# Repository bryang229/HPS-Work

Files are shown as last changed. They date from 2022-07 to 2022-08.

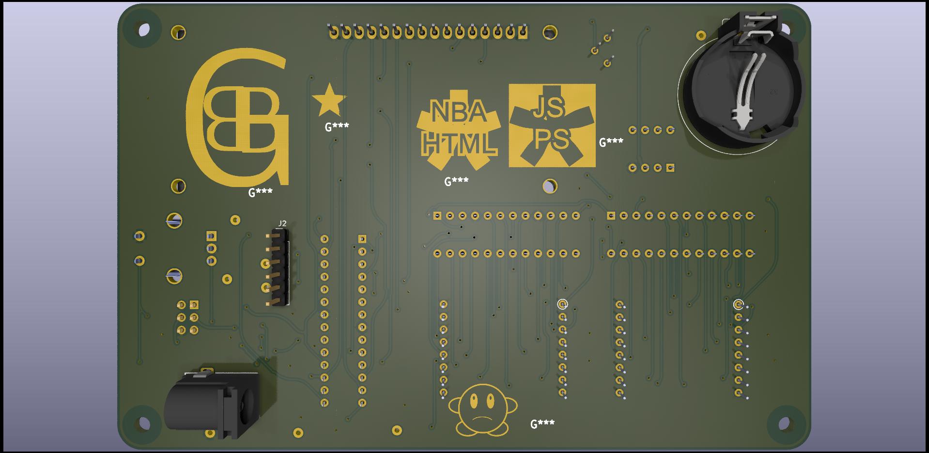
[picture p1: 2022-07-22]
Clock CAD & Code/Clock/Clock backside raytracing.jpg

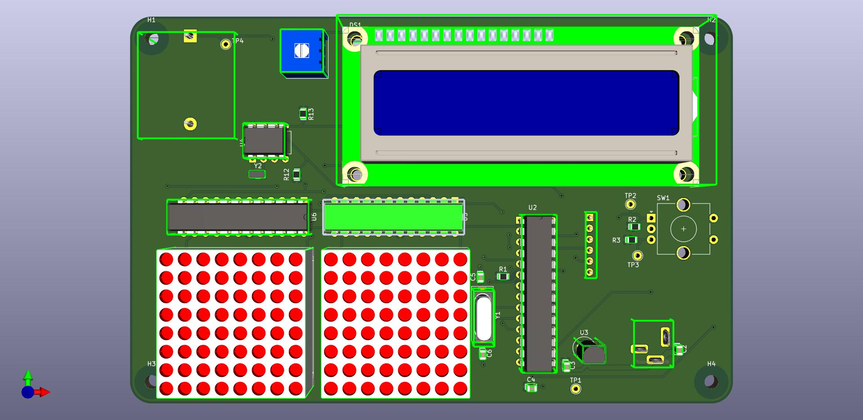
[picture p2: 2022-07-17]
Clock CAD & Code/Clock/Clock.jpg

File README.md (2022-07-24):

# About

This is a Clock PCB designed using KiCAD!

The code working with the clock is also included written in the arduino editor!

All parts in the clock are from [this library](https://github.com/hps-matthew/hps-kicad-library) (very useful !).

This is a project under the Hardware Product Spring program ! (Hence HPS) 

More documentation about the code is to come.

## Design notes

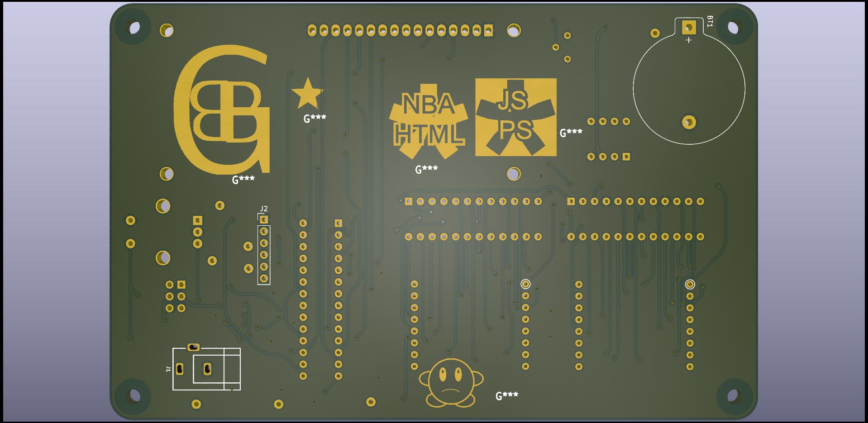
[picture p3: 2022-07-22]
Clock CAD & Code/Clock/Clock Back PCB.jpg

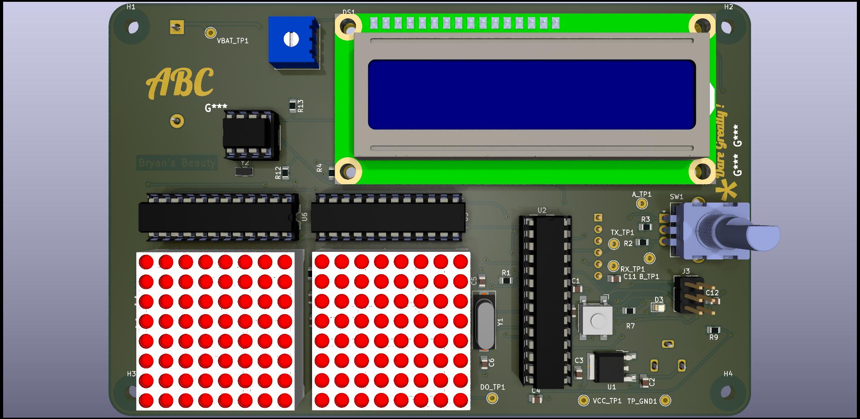
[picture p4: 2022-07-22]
Clock CAD & Code/Clock/Clock raytracing.jpg

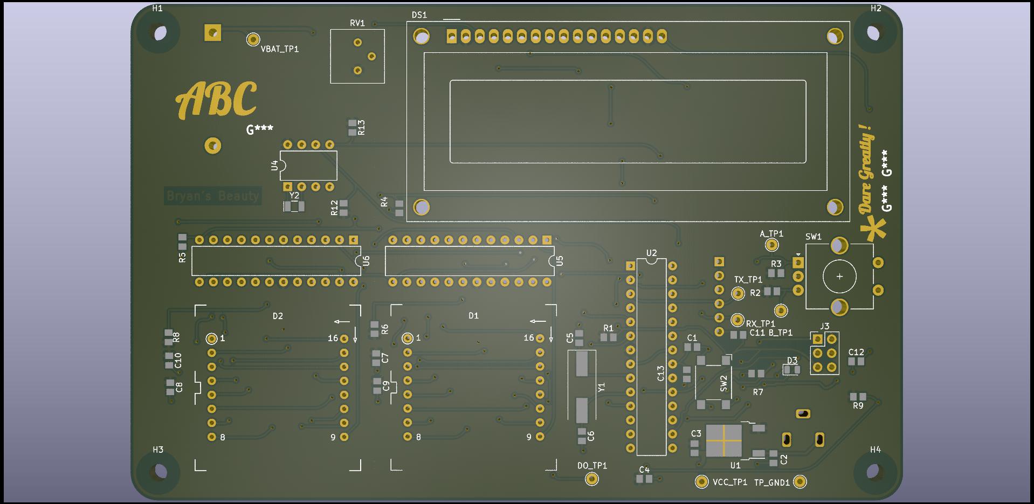
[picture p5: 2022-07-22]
Clock CAD & Code/Clock/Clock Front PCB.jpg

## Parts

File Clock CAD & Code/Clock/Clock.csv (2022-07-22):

Id | Designator | Package | Quantity | Designation | Supplier and ref
1 | C11,C13,C3,C10,C4,C9,C1 | C_0805_2012Metric | 7 | C_0805_0.1uf
2 | Y2 | Crystal_SMD_2Pin_3.2x1.5mm | 1 | Crystal_32768Hz
3 | R1 | R_0805_2012Metric | 1 | 10KΩ
4 | U5,U6 | DIP-24_W7.62mm | 2 | MAX7219
5 | H2,H3,H1,H4 | MountingHole_3.2mm_M3 | 4 | MountingHole
6 | C6,C5 | C_0805_2012Metric | 2 | 22p
7 | SW1 | RotaryEncoder_TT_EN11-Switch_Vertical_H20mm_CircularMountingHoles | 1 | RotaryEncoder_Switch
8 | R7 | R_0805_2012Metric | 1 | R_0805_2.2K
9 | R6,R8 | R_0805_2012Metric | 2 | R_0805_22K
10 | A_TP1,DO_TP1,TX_TP1,VCC_TP1,RX_TP1,B_TP1,VBAT_TP1,TP_GND1 | TestPoint_THTPad_D2.0mm_Drill1.0mm | 8 | TestPoint
11 | U1 | TO-252-2 | 1 | L7805
12 | R2,R4,R9,R5,R3 | R_0805_2012Metric | 5 | R_0805_10K
13 | Y1 | Crystal_SMD_HC49-SD | 1 | Crystal 16MHZ
14 | D3 | LED_0805_2012Metric | 1 | LED_0805
15 | C7,C8 | C_0805_2012Metric | 2 | C_0805_10uf
16 | R12,R13 | R_0805_2012Metric | 2 | R_0805_4.7K
17 | DS1 | TC1602A-01T | 1 | TC1602A-01T
18 | U4 | DIP-8_W7.62mm | 1 | DS1307_DIP-8
19 | C12,C2 | C_0805_2012Metric | 2 | C_0805_1uf
20 | U2 | DIP-28_W7.62mm | 1 | ATmega328-PU
21 | RV1 | Potentiometer_Bourns_3386P_Vertical | 1 | R_POT_10K
22 | D2,D1 | KWM-30881CVB | 2 | KWM-30881CVB
23 | SW2 | SW_SPST_Omron_B3FS-100xP | 1 | Omron_B3F_SPST
24 | J3 | PinHeader_2x03_P2.54mm_Vertical | 1 | Conn_02x03_Odd_Even
25 | BT1 | BatteryHolder_Keystone_106_1x20mm | 1 | Battery_Cell
26 | J2 | PinHeader_1x06_P2.54mm_Vertical | 1 | Conn_01x06
27 | J1 | PJ-102AH | 1 | PJ-102AH

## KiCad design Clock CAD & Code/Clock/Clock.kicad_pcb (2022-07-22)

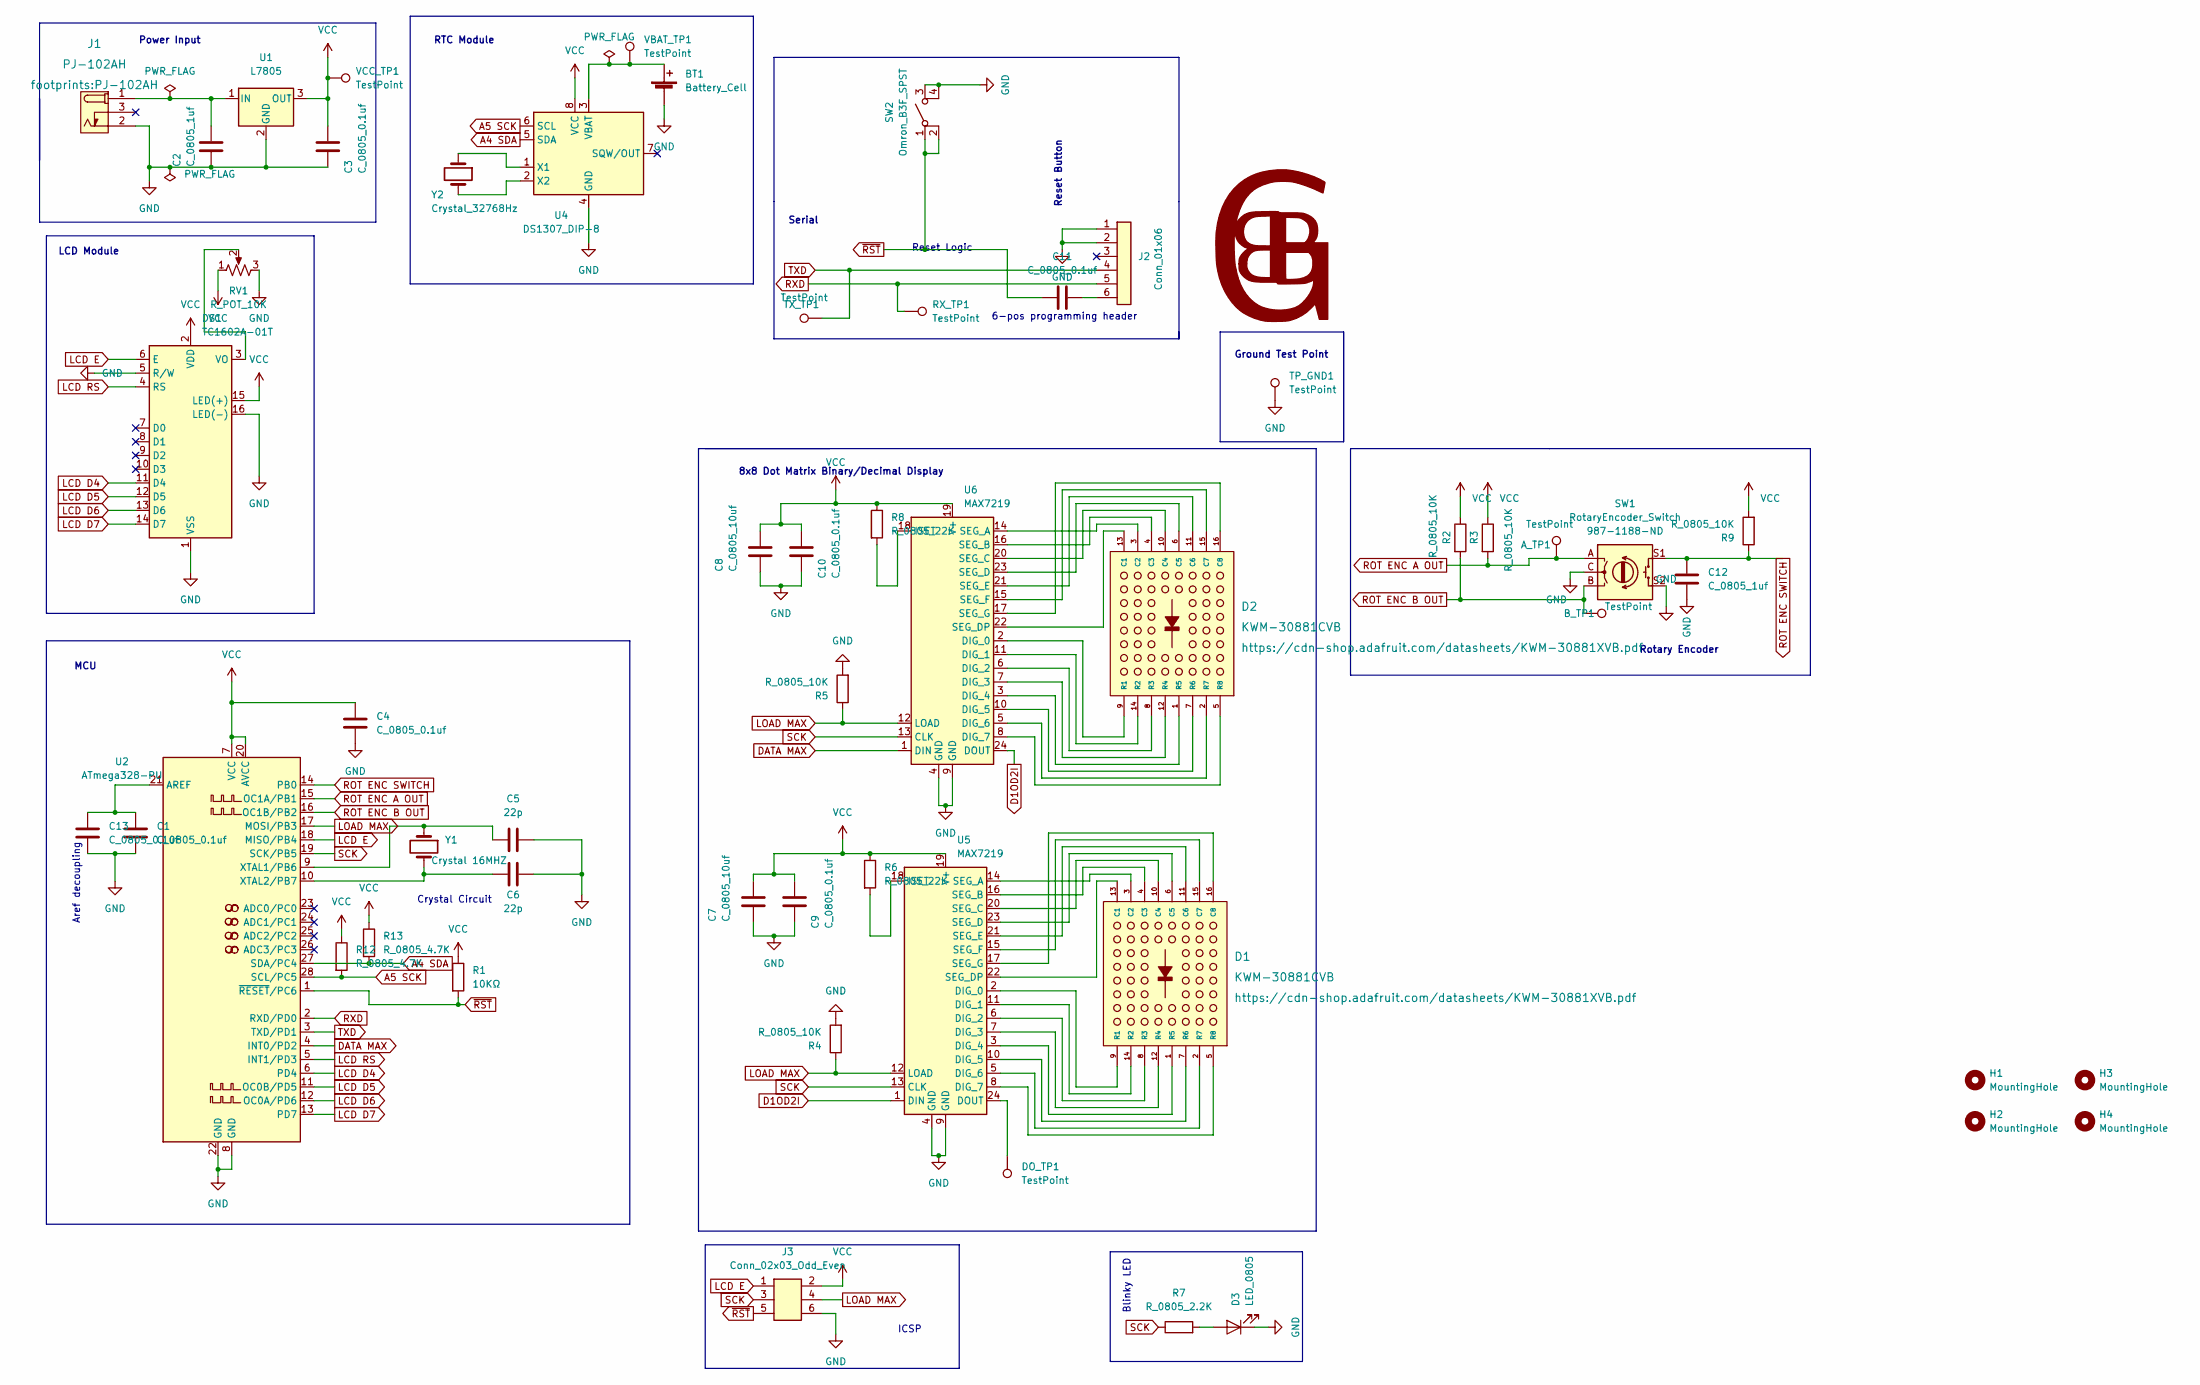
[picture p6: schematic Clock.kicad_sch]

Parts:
A_TP1: TestPoint; TestPoint_THTPad_D2.0mm_Drill1.0mm
BT1: Battery_Cell; BatteryHolder_Keystone_106_1x20mm; MPN BS-7; Digikey PN BS-7-ND
B_TP1: TestPoint; TestPoint_THTPad_D2.0mm_Drill1.0mm
C1, C3, C4, C9, C10, C11, C13: C_0805_0.1uf; C_0805_2012Metric; Voltage N/A; Tolerance N/A; MPN 08055C104KAT2A; Digikey PN 478-1395-1-ND
C2, C12: C_0805_1uf; C_0805_2012Metric; Voltage N/A; Tolerance N/A; MPN CC0805KKX7R8BB105; Digikey PN 311-1456-1-ND
C5, C6: 22p; C_0805_2012Metric; Voltage N/A; Tolerance N/A; MPN CC0805JRNPO9BN220; Digikey PN 311-1103-1-ND
C7, C8: C_0805_10uf; C_0805_2012Metric; Voltage N/A; Tolerance N/A; MPN GRM21BR61E106KA73L; Digikey PN 490-5523-1-ND
D1, D2: KWM-30881CVB; MPN KWM-30881CVB; Digikey PN N/A
D3: LED_0805; LED_0805_2012Metric; MPN 150080RS75000; Digikey PN 732-4984-1-ND
DO_TP1: TestPoint; TestPoint_THTPad_D2.0mm_Drill1.0mm
DS1: TC1602A-01T; MPN 1447; Digikey PN 1528-2212-ND
H1, H2, H3, H4: MountingHole; MountingHole_3.2mm_M3
J1: PJ-102AH; MPN PJ-102AH; Digikey PN CP-102AH-ND
J2: Conn_01x06; PinHeader_1x06_P2.54mm_Vertical; MPN 61300611121; Digikey PN 732-5319-ND
J3: Conn_02x03_Odd_Even; PinHeader_2x03_P2.54mm_Vertical; MPN PRPC003DAAN-RC; Digikey PN S2011EC-03-ND
R1: 10KΩ; R_0805_2012Metric; Tolerance N/A; MPN RC0805FR-0710KL; Digikey PN 311-10.0KCRCT-ND
R2, R3, R4, R5, R9: R_0805_10K; R_0805_2012Metric; Tolerance N/A; MPN RC0805FR-0710KL; Digikey PN 311-10.0KCRCT-ND
R6, R8: R_0805_22K; R_0805_2012Metric; Tolerance N/A; MPN RC0805FR-0722KL; Digikey PN 311-22.0KCRCT-ND
R7: R_0805_2.2K; R_0805_2012Metric; Tolerance N/A; MPN N/A; Digikey PN 311-2.20KCRCT-ND
R12, R13: R_0805_4.7K; R_0805_2012Metric; Tolerance N/A; MPN RC0805FR-074K7L; Digikey PN 311-4.70KCRCT-ND
RV1: R_POT_10K; Potentiometer_Bourns_3386P_Vertical; MPN 3386P-1-103TLF; Digikey PN 3386P-103TLF-ND
RX_TP1: TestPoint; TestPoint_THTPad_D2.0mm_Drill1.0mm
SW1: RotaryEncoder_Switch; RotaryEncoder_TT_EN11-Switch_Vertical_H20mm_CircularMountin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; Digikey PN 987-1188-ND
SW2: Omron_B3F_SPST; SW_SPST_Omron_B3FS-100xP; MPN B3FS-1000P; Digikey PN SW423CT-ND
TP_GND1: TestPoint; TestPoint_THTPad_D2.0mm_Drill1.0mm
TX_TP1: TestPoint; TestPoint_THTPad_D2.0mm_Drill1.0mm
U1: L7805; TO-252-2; MPN L7805CDT-TR; Digikey PN 497-7255-1-ND
U2: ATmega328-PU; DIP-28_W7.62mm; MPN ED281DT; Digikey PN ED3050-5-ND
U4: DS1307_DIP-8; DIP-8_W7.62mm; MPN A 08-LC-TT; Digikey PN AE9986-ND
U5, U6: MAX7219; DIP-24_W7.62mm; MPN ED241DT; Digikey PN ED3049-5-ND
VBAT_TP1: TestPoint; TestPoint_THTPad_D2.0mm_Drill1.0mm
VCC_TP1: TestPoint; TestPoint_THTPad_D2.0mm_Drill1.0mm
Y1: Crystal 16MHZ; Crystal_SMD_HC49-SD; MPN ECS-160-20-5PXDN-TR; Digikey PN XC1299CT-ND
Y2: Crystal_32768Hz; Crystal_SMD_2Pin_3.2x1.5mm; MPN Q 0,032768-JTX310-12,5-20-T1-HMR-50K-LF; Digikey PN 1908-1314-1-ND

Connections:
A4 SDA: R13.2, U2.27 (SDA/PC4), U4.5 (SDA)
A5 SCK: R12.2, U2.28 (SCL/PC5), U4.6 (SCL)
D1OD2I: U5.1 (DIN), U6.24 (DOUT)
DATA MAX: U2.4 (INT0/PD2), U6.1 (DIN)
GND: BT1.2 (-), C1.2, C2.2, C3.2, C4.2, C5.2, C6.2, C7.2, C8.2, C9.2, C10.2, C12.1, C13.2, D3.1 (K), DS1.1 (VSS), DS1.5 (R/W), DS1.16 (LED(-)), J1.2 (OUT), J2.1, J2.2, J3.6, R4.2, R5.2, RV1.3, SW1.C, SW1.S2, SW2.3 (B), SW2.4 (B), TP_GND1.1, U1.2 (GND), U2.8 (GND), U2.22 (GND), U4.4 (GND), U5.4 (GND), U5.9 (GND), U6.4 (GND), U6.9 (GND)
LCD D4: DS1.11 (D4), U2.6 (PD4)
LCD D5: DS1.12 (D5), U2.11 (OC0B/PD5)
LCD D6: DS1.13 (D6), U2.12 (OC0A/PD6)
LCD D7: DS1.14 (D7), U2.13 (PD7)
LCD E: DS1.6 (E), J3.1, U2.18 (MISO/PB4)
LCD RS: DS1.4 (RS), U2.5 (INT1/PD3)
LOAD MAX: J3.4, R4.1, R5.1, U2.17 (MOSI/PB3), U5.12 (LOAD), U6.12 (LOAD)
unnamed: BT1.1 (+), U4.3 (VBAT), VBAT_TP1.1
unnamed: C1.1, C13.1, U2.21 (AREF)
unnamed: C2.1, J1.1 (POLE), U1.1 (IN)
unnamed: C5.1, U2.9 (XTAL1/PB6), Y1.1
unnamed: C6.1, U2.10 (XTAL2/PB7), Y1.2
unnamed: C11.2, J2.6
unnamed: D1.1 (R5), U5.3 (DIG_4)
unnamed: D1.2 (R7), U5.5 (DIG_6)
unnamed: D1.3 (C2), U5.14 (SEG_A)
unnamed: D1.4 (C3), U5.16 (SEG_B)
unnamed: D1.5 (R8), U5.8 (DIG_7)
unnamed: D1.6 (C5), U5.23 (SEG_D)
unnamed: D1.7 (R6), U5.10 (DIG_5)
unnamed: D1.8 (R3), U5.6 (DIG_2)
unnamed: D1.9 (R1), U5.2 (DIG_0)
unnamed: D1.10 (C4), U5.20 (SEG_C)
unnamed: D1.11 (C6), U5.21 (SEG_E)
unnamed: D1.12 (R4), U5.7 (DIG_3)
unnamed: D1.13 (C1), U5.22 (SEG_DP)
unnamed: D1.14 (R2), U5.11 (DIG_1)
unnamed: D1.15 (C7), U5.15 (SEG_F)
unnamed: D1.16 (C8), U5.17 (SEG_G)
unnamed: D2.1 (R5), U6.3 (DIG_4)
unnamed: D2.2 (R7), U6.5 (DIG_6)
unnamed: D2.3 (C2), U6.14 (SEG_A)
unnamed: D2.4 (C3), U6.16 (SEG_B)
unnamed: D2.5 (R8), U6.8 (DIG_7)
unnamed: D2.6 (C5), U6.23 (SEG_D)
unnamed: D2.7 (R6), U6.10 (DIG_5)
unnamed: D2.8 (R3), U6.6 (DIG_2)
unnamed: D2.9 (R1), U6.2 (DIG_0)
unnamed: D2.10 (C4), U6.20 (SEG_C)
unnamed: D2.11 (C6), U6.21 (SEG_E)
unnamed: D2.12 (R4), U6.7 (DIG_3)
unnamed: D2.13 (C1), U6.22 (SEG_DP)
unnamed: D2.14 (R2), U6.11 (DIG_1)
unnamed: D2.15 (C7), U6.15 (SEG_F)
unnamed: D2.16 (C8), U6.17 (SEG_G)
unnamed: D3.2 (A), R7.2
unnamed: DO_TP1.1, U5.24 (DOUT)
unnamed: DS1.3 (VO), RV1.2
unnamed: R6.2, U5.18 (ISET)
unnamed: R8.2, U6.18 (ISET)
unnamed: U4.1 (X1), Y2.1
unnamed: U4.2 (X2), Y2.2
ROT ENC A OUT: A_TP1.1, R3.2, SW1.A, U2.15 (OC1A/PB1)
ROT ENC B OUT: B_TP1.1, R2.2, SW1.B, U2.16 (OC1B/PB2)
ROT ENC SWITCH: C12.2, R9.1, SW1.S1, U2.14 (PB0)
RXD: J2.5, RX_TP1.1, U2.2 (RXD/PD0)
SCK: J3.3, R7.1, U2.19 (SCK/PB5), U5.13 (CLK), U6.13 (CLK)
TXD: J2.4, TX_TP1.1, U2.3 (TXD/PD1)
VCC: C3.1, C4.1, C7.1, C8.1, C9.1, C10.1, DS1.2 (VDD), DS1.15 (LED(+)), J3.2, R1.1, R2.1, R3.1, R6.1, R8.1, R9.2, R12.1, R13.1, RV1.1, U1.3 (OUT), U2.7 (VCC), U2.20 (AVCC), U4.8 (VCC), U5.19 (V+), U6.19 (V+), VCC_TP1.1
~RST: C11.1, J3.5, R1.2, SW2.1 (A), SW2.2 (A), U2.1 (~RESET/PC6)

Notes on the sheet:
Ground Test Point
8x8 Dot Matrix Binary/Decimal Display
Power Input
Reset Button
Serial
Blinky LED
ICSP
RTC Module
Rotary Encoder
Aref decoupling
6-pos programming header
Crystal Circuit
LCD Module
MCU
Reset Logic

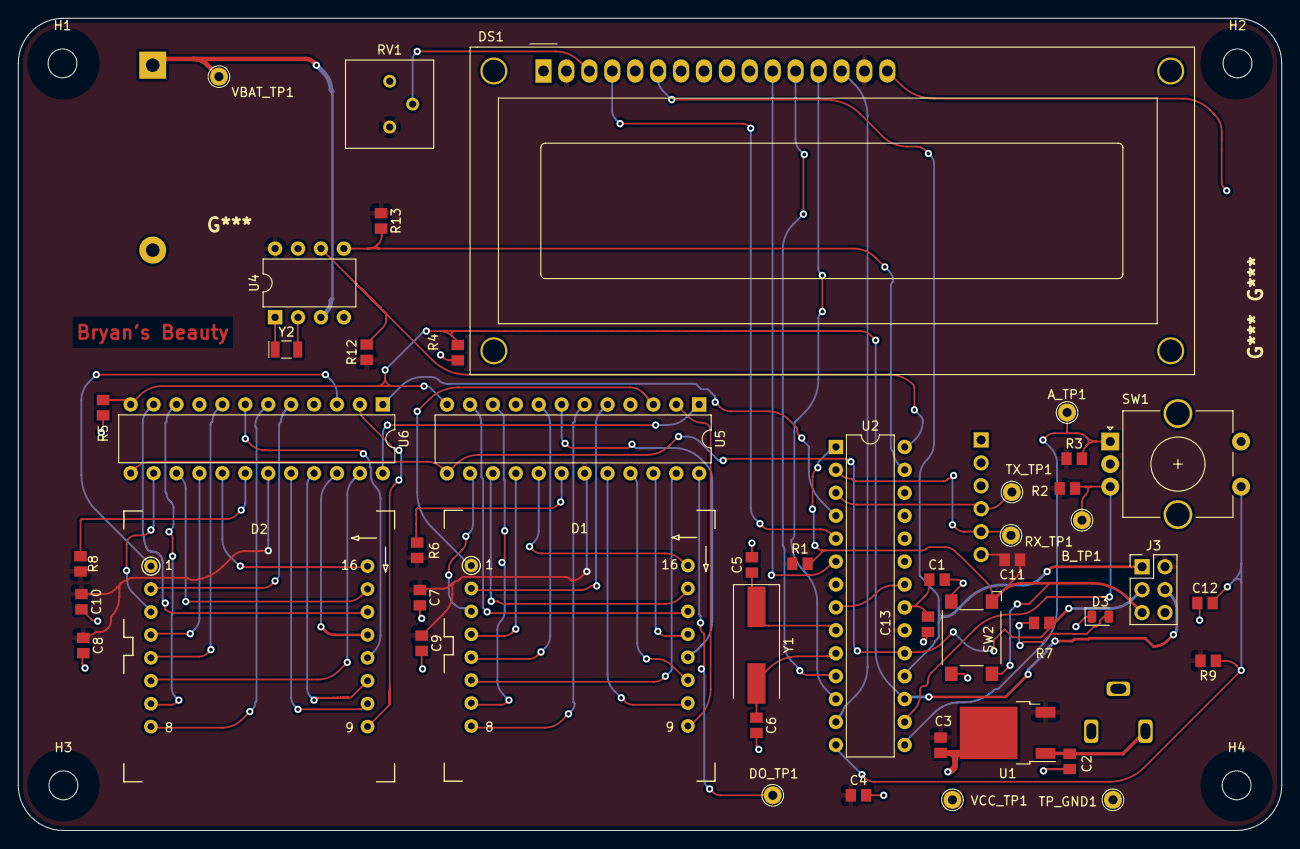
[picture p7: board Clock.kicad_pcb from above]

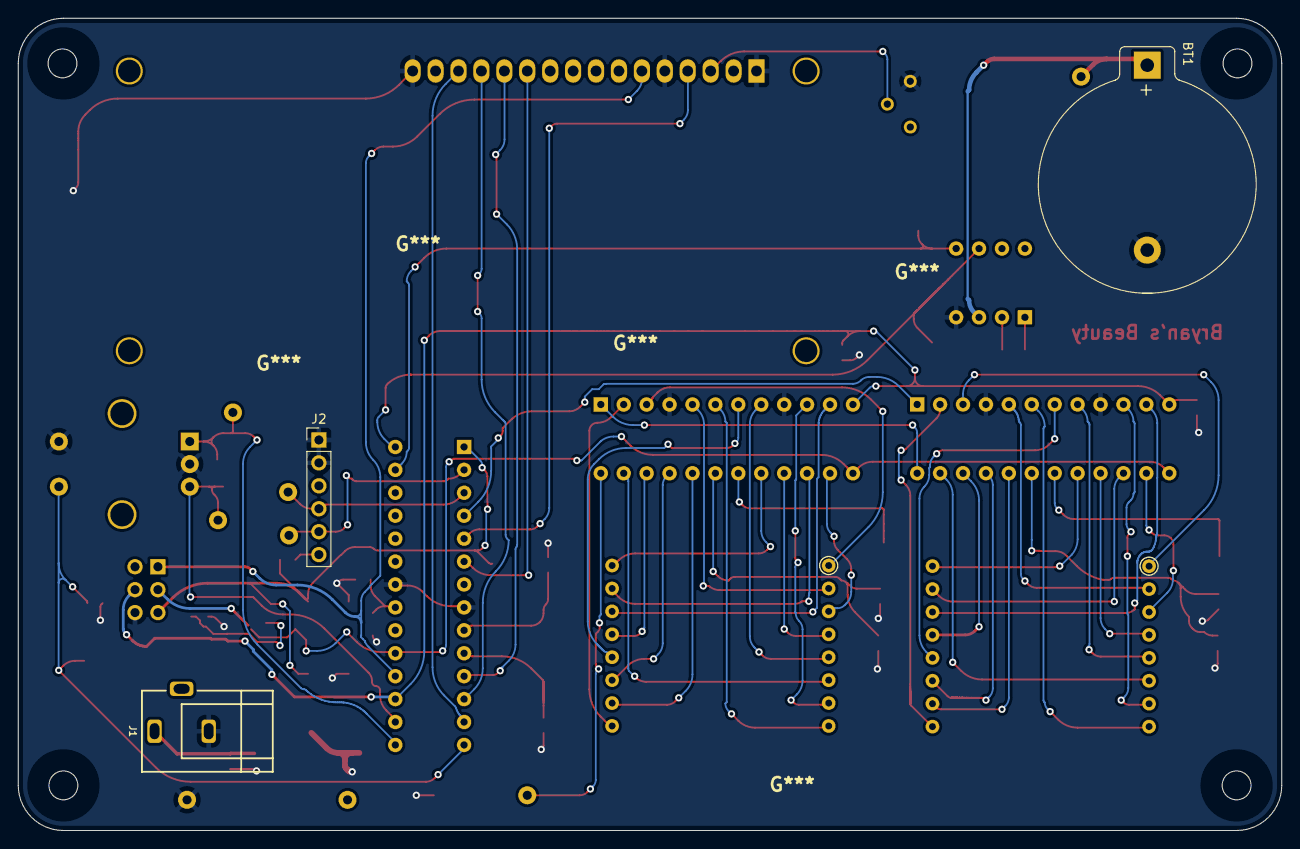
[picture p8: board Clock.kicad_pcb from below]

Board: 2 copper layers, 140.0 x 90.0 mm, 54 parts (3 on the bottom side), 65 nets.

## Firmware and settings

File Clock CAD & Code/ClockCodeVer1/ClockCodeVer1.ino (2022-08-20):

#include "RotaryEncoder.h"
//LCD Library
#include <LiquidCrystal.h>

//                RS,E,D4-D7
LiquidCrystal lcd(10, 12, 4, 5, 6, 7);

//Libraries for the 8x8 Displays
#include <LedControl.h>
#include "Wire.h"
#include "RTClib.h"

//Pins for 8x8 Based off pin mapping
#define CLK_PIN 13
#define DATA_PIN 11
#define MAX_DEVICES 2
#define CS_PIN 9


RTC_DS1307 rtc;
LedControl myDisplay(DATA_PIN, CLK_PIN, CS_PIN, MAX_DEVICES);

//Rotary Enc Pins based off pin mapping
#define pinA 2
#define pinB 3
#define SwitchPin 8

RotaryEncoder *encoder = nullptr; //Creating a pointer for my encoder instance
int dir;                 //Creating my direction variable which will change with interrupts
//-1 -> Counter Clock Wise || 0 -> Not moving || 1 -> Clock Wise ^^^^^^^^^^^^^^^^^^^^^^^^^^

//Setting up Interrupt
void checkPosition() {
  encoder->tick(); // just call tick() to check the state.
  //  dir = (int)(encoder->getDirection()); //Updating the direction variable
}

//Display variables (8x8)
int on = 0xff;
int off = 0x00;
int zero[] = {0x7c, 0xfe, 0xe3, 0xb3, 0x9a, 0xfe, 0x7c, 0x0};
int one[] = {0x80, 0x84, 0xff, 0xff, 0x80, 0x80, 0x0, 0x1};
int two[] = {0xc4, 0xe6, 0xb3, 0x93, 0xde, 0xcc, 0x1, 0x0};
int three[] = {0x44, 0xc6, 0x93, 0x93, 0xfe, 0x6c, 0x1, 0x1};
int four[] = {0x30, 0x38, 0x2d, 0xa7, 0xfe, 0xff, 0xa0, 0x0};
int five[] = {0x4e, 0xce, 0x8b, 0x8b, 0xfa, 0x73, 0x0, 0x1};
int six[] = {0x78, 0xfc, 0x97, 0x93, 0xf2, 0x61, 0x1, 0x0};
int seven[] = {0x6, 0x6, 0xe3, 0xf3, 0x1e, 0xf, 0x1, 0x1};
int eight[] = {0x6c, 0xfe, 0x93, 0x93, 0xff, 0x6c, 0x0, 0x0};
int nine[] = {0xc, 0x9e, 0x93, 0xd3, 0x7f, 0x3c, 0x0, 0x1};


//Labels for the weeks (daysOfTheWeek has Saturday twice due to an error when generating the day of the week)
const char *daysOfTheWeek[] = {"Saturday", "Sunday", "Monday", "Tuesday", "Wednesday", "Thursday", "Friday", "Saturday"};
const char *months[] = {"N/A", "Jan", "Feb", "Mar", "Apr", "May", "June", "July", "Aug",
                        "Sep", "Oct", "Nov", "Dec"
                       };
const char *dates[] = {"0", "1", "2", "3", "4", "5", "6", "7", "8", "9", "10", "11", "12", "13", "14", "15", "16", "17", "18", "19", "20", "21", "22", "23", "24", "25", "26", "27", "28", "29", "30", "31"};

//Global D-M-Y Variables for the date
int month;
int year;
int day;
//Global Time variables
int seconds = 0;
int minute = 0;
int hour = 0;
// bool isBinaryMode = true; //Is used for changing modes (This feature has not Been added yet)

//Used for HMS formatting
boolean isFirstTime = false;

//This will be used to extract the formatted date
char *date[2];

int displayMode = 0;
//-1: Binary Mode ||0: Hours Minutes Seconds || 1: Decimal Mode
//Used for binary mode
int binaryImage[] = {0, 0, 0, 0, 0, 0};


void setup() {
  //Starting up 8x8
  myDisplay.shutdown(0, false);
  myDisplay.shutdown(1, false);
  myDisplay.setIntensity(0, 6);
  myDisplay.setIntensity(1, 6);
  myDisplay.clearDisplay(0);
  myDisplay.clearDisplay(1);
  //Setting up Rot Enc (LatchMode::FOUR3 is for when pinA and pinB are normally high)
  encoder = new RotaryEncoder(pinA, pinB, RotaryEncoder::LatchMode::FOUR3);
  //Attaching interrupts to pinA and pinB on falling edge
  attachInterrupt(digitalPinToInterrupt(pinA), checkPosition, FALLING);
  attachInterrupt(digitalPinToInterrupt(pinB), checkPosition, FALLING);
  //begining lcd
  lcd.begin(16, 2);
  lcd.clear();
  //Setting up button on the Rot Enc
  pinMode(SwitchPin, INPUT_PULLUP);
  Serial.begin(9600);

  //Setting up RTC
  if (! rtc.begin()) {
    Serial.println("Couldn't find RTC");
    Serial.flush();
    while (1) delay(10);
  }
//  if (! rtc.isrunning()) {
    Serial.println("RTC is NOT running, let's set the time!");
    rtc.adjust(DateTime(F(__DATE__), F(__TIME__)));
//  }
  //Setting up date for the first time and giving Date variables values
  DateTime now = rtc.now();
  year = (int)(now.year());
  day = (int)(now.day());
  month = (int)(now.month());

  //Showing date on LCD
  showDate();
}

int setBinaryFmt() {
  for (int i = 0; i < 6; i++) {
    binaryImage[i] = ((seconds >> i) & 1);
  }
}

void binaryMode() {
  setBinaryFmt();
  //right side first
  myDisplay.setRow(0, 0, off);
  myDisplay.setRow(0, 1, binaryImage[2] > 0 ? on : off);
  myDisplay.setRow(0, 2, off);
  myDisplay.setRow(0, 3, binaryImage[1] > 0 ? on : off);
  myDisplay.setRow(0, 4, binaryImage[1] > 0 ? on : off);
  myDisplay.setRow(0, 5, off);
  myDisplay.setRow(0, 6, binaryImage[0] > 0 ? on : off);
  myDisplay.setRow(0, 7, off);
  delay(10);

  //left side now
  myDisplay.setRow(1, 0, off);
  myDisplay.setRow(1, 1, binaryImage[5] > 0 ? on : off);
  myDisplay.setRow(1, 2, off);
  myDisplay.setRow(1, 3, binaryImage[4] > 0 ? on : off);
  myDisplay.setRow(1, 4, binaryImage[4] > 0 ? on : off);
  myDisplay.setRow(1, 5, off);
  myDisplay.setRow(1, 6, binaryImage[3] > 0 ? on : off);
  myDisplay.setRow(1, 7, off);

  delay(10);
}

int getNumber(int num, int row) {
  //  int tempNum = 0;
  switch (num) {
    case 0: return zero[row];
    case 1: return one[row];
    case 2: return two[row];
    case 3: return three[row];
    case 4: return four[row];
    case 5: return five[row];
    case 6: return six[row];
    case 7: return seven[row];
    case 8: return eight[row];
    case 9: return nine[row];
    default: return zero[0];
  }
}

void decimalMode() {
  int right = seconds % 10;
  for (int j = 7; j > 0; j--)
    myDisplay.setRow(0, j, getNumber(right, j));
  delay(10);

  int left = floor(seconds / 10);
  for (int i = 7; i > 0; i--)
    myDisplay.setRow(1, i, getNumber(left, i));
  delay(10);

}

//Used for giving the M-S weekday
int getWeekIndex(int m, int d, int y) {
  Serial.print("Dates given: ");
  Serial.print(m);
  Serial.print("-");
  Serial.print(d);
  Serial.print("-");
  Serial.println(y);

  int monthKeys[] = {0, 1, 4, 4, 0, 2, 5, 0, 3, 6, 1, 4, 6};
  int index = String(y).substring(2).toInt();
  index = floor(index / 4);
  index += d;
  index += monthKeys[m];
  if ( m == 0 || ( m == 1 && y % 4 == 0 && (y % 100 != 0 || y % 400 == 0 && y % 100 == 0)))
    index--;
  int topTwo = floor(y / 100);
  while (topTwo < 20)
    topTwo += 4;
  if ((topTwo - 17) % 4 == 0)
    index += 4;
  else if ((topTwo - 18) % 4 == 0)
    index += 2;
  else if ((topTwo - 19) % 4 == 0)
    index += 0;
  else if ((topTwo - 20) % 4 == 0)
    index += 6;
  index += String(y).substring(2).toInt();
  index %= 7;

  return index;
}

//This gets the int values of M and D and gets the String version out their respective Arr
void formatDate() {
  date[0] = months[month];
  date[1] = dates[day];
}

//Shows current set date onto the LCD
void showDate() {
  formatDate(); //Formats date
  lcd.clear();
  for (int i = 0; i < 2; i++) {
    lcd.print(date[i]); //Prints all things from the date arr
    lcd.print(" ");
  }
  lcd.print(year); //prints year
  lcd.print(" ");
  lcd.setCursor(0, 1); //next line
  lcd.print(daysOfTheWeek[getWeekIndex(month, day, year)]); //prints the M-S date based of the current M-D-Y
}

//Shows date onto the LCD (Based off input)
void showDate(int m, int d, int y) {
  char *tempDates[] = {months[m], dates[d]};
  lcd.clear();
  for (int i = 0; i < 2; i++) {
    lcd.print(tempDates[i]);
    lcd.print(" ");
  }
  lcd.print(y);
  lcd.print(" ");
  lcd.setCursor(0, 1);
  lcd.print(daysOfTheWeek[getWeekIndex(m, d, y)]);

}

//Sets global date (Month, Day or Year)
//The following menus will have the same skeleton for Menu Scrolling and selection
void setDate() {
  boolean setDateMode = true; //For staying in this Menu
  char *datesMenu[] = {"Set Month", "Set Day", "Set Year", "Exit Menu"};
  int menuLen = 3; //For knowing the end of the list
  int menuPos = 0; //Users Position in the list

  lcd.clear();
  lcd.print(datesMenu[menuPos]); //Showing the users position in the menu on the LCD

  while (setDateMode) {
    int tempMenuPos = menuPos; //Knowing when the user moved
    dir = (int)(encoder->getDirection()); //Getting the direction
    if (dir != 0) { //Checking for movement
      if (dir < 0) {
        menuPos += menuPos > 0 ? dir : menuLen; //making sure it doesn't go below 0
      } else {
        menuPos += menuPos < menuLen ? dir : -1 * menuLen; //making sure it is at max the menuLen or back to 0
      }
      if (menuPos > menuLen || menuPos < 0)
        menuPos = 0; //Checking for any crazy errors and forcing it back to 0
      delay(25);
    }

    if (menuPos != tempMenuPos) { //only updating when user scrolls
      lcd.clear();
      lcd.print(datesMenu[menuPos]);
      tempMenuPos = menuPos;
      delay(50);
    }

    DateTime now = rtc.now();   //Checking for a change of time to display time on the 8x8
    int tempS = seconds;
    seconds = int(now.second());
    if (tempS != seconds)
      updateTime();

    //Checking for a button press on Rot Enc
    if (checkButton()) {
      switch (menuPos) { //Running different menus based off the user's position and deboucing
        //0 -> Month || 1 -> Day || 2 -> Year || 3 -> Exit (Settings Menu)
        case 0:
          setDateMode = false;
          delay(150);
          changeMonth(); break;
        case 1:
          setDateMode = false;
          delay(150);
          changeDate(); break;
        case 2:
          setDateMode = false;
          delay(150);
          changeYear(); break;
        case 3:
          setDateMode = false; displaySettings(); break;
        default:
          Serial.print("Error: ");
          Serial.println(menuPos); break;
      }
    }
  }
}

//Changing Global month menu
//Following change methods are very similar to this one
void changeMonth() {
  boolean settingMonth = true;
  int monthPos = month;           //user position
  showDate(monthPos, day, year);  //showing the date the user has selected on LCD
  int monthLen = 13;              //Max value Important since months[13] does not exist it is for handling an exit
  while (settingMonth) {
    dir = (int)(encoder->getDirection());  //Getting direction
    int tempMonthPos = monthPos;           //Used to make sure the user moved
    if (dir != 0) {                        //handling a Non-Zero direction
      if (dir < 0) {
        monthPos += monthPos > 1 ? dir : monthLen - 1;    //Making sure it's above 1
      } else {
        monthPos += monthPos < monthLen ? dir : -1 * (monthLen - 1); //making sure it's at max menuLen or back to 0
      }
      if (monthPos > monthLen || monthPos < 1) //Checking for any crazy errors and bringing it back to 1 if so
        monthPos = 1;
      delay(25);
    }
    if (monthPos != tempMonthPos) { //Checking for movement and displaying said movement
      Serial.print("Month Pos: ");
      Serial.print(monthPos);
      Serial.print("\t Temp Month Pos: ");
      Serial.println(tempMonthPos);
      if (monthPos == 13) { //Checking for 13 and showing the exit menu since we cannot call showDate with 13 as the month value
        lcd.clear();
        lcd.print("Exit Menu");
      } else if (monthPos < 13 && monthPos >= 0) {
        showDate(monthPos, day, year);
      }
      delay(10);
    }
    DateTime now = rtc.now();   //Updating 8x8 only when time changes
    int tempS = seconds;
    seconds = int(now.second());
    if (tempS != seconds)
      updateTime();

    if (checkButton()) { //Checking for button input
      if (monthPos == 13) {
        settingMonth = false;
        delay(150);
        setDate();
      }
      else {
        month = monthPos;
        delay(150);
        showDate();
      }
    }
  }
}

//Similar as the change month function
//Pretty much the above with different values of max position
void changeDate() {
  boolean settingDay = true;
  int dayPos = day;
  showDate(month, dayPos, year);
  int dayLen = 32;
  while (settingDay) {
    dir = (int)(encoder->getDirection());
    int tempDayPos = dayPos;
    if (dir != 0) {
      if (dir < 0) {
        dayPos += dayPos > 1 ? dir : dayLen - 1;
      } else {
        dayPos += dayPos < dayLen ? dir : -1 * (dayLen - 1);
      }
      if (dayPos > dayLen || dayPos < 1)
        dayPos = 1;
      delay(10);
    }
    if (dayPos != tempDayPos) {
      Serial.print("Day Pos: ");
      Serial.print(dayPos);
      Serial.print("\t Temp Day Pos: ");
      Serial.println(tempDayPos);
      if (dayPos == 32) {
        lcd.clear();
        lcd.print("Exit Menu");
      } else if (dayPos < 32 && dayPos >= 0) {
        showDate(month, dayPos, year);
      }
      delay(25);
    }
    DateTime now = rtc.now();

    int tempS = seconds;
    seconds = int(now.second());
    if (tempS != seconds)
      updateTime();

    if (checkButton()) {
      if (dayPos == 32) {
        settingDay = false;
        delay(150);
        setDate();
      }
      else {
        day = dayPos;
        delay(150);
        showDate();
      }
    }
  }
}

//Similar to the above change functions with a small change on the exit menu
void changeYear() {
  boolean settingYear = true;
  int yearPos = year;
  showDate(month, day, yearPos);
  while (settingYear) {
    dir = (int)(encoder->getDirection());
    int tempYearPos = yearPos;
    if (dir != 0) {
      yearPos += dir;
      delay(10);
    }
    if (yearPos != tempYearPos) {
      Serial.print("Year Pos: ");
      Serial.print(yearPos);
      Serial.print("\t Temp Year Pos: ");
      Serial.println(tempYearPos);
      //Mid year so it is the exit menu
      if (yearPos == 2016) {
        lcd.clear();
        lcd.print("Exit Menu");
      } else {
        showDate(month, day, yearPos);
      }
      delay(50);
    }
    DateTime now = rtc.now();

    int tempS = seconds;
    seconds = int(now.second());
    if (tempS != seconds)
      updateTime();

    if (checkButton()) {
      if (yearPos == 2016) { //Had to pick a year to be the exit screen and 2016 was trash so it got it
        settingYear = false;
        delay(150);
        setDate();
      }
      else {
        year = yearPos;
        delay(150);
        showDate();
      }
    }
  }
}

void disSettings() {
  char *menu[] = {"Hour Minutes Seconds Mode", "Decimal Mode", "Binary Mode", "Exit Menu"};
  int menuLen = 4;
  boolean disMode = true;
  int disPos = 0;
  //Lazy fix
  lcd.clear();
  lcd.print("Hour Minutes");
  lcd.setCursor(0, 1);
  lcd.print("Seconds Mode");
  while (disMode) {
    dir = (int)(encoder->getDirection());       //updating direction to see if Rot Enc has been turned
    int tempDisPos = disPos;          //This is for making sure the user moved in the menu
    if (dir != 0) {
      if (dir < 0) {
        disPos += disPos > 0 ? dir : menuLen;  //making sure it doesn't go below 0 and wrap around
      } else {
        disPos += disPos < menuLen ? dir : -1 * menuLen;  //making it wrap around if it goes over the menu len
      }
      if (disPos >= menuLen || disPos < 0) //fixing any crazy errors
        disPos = 0;
      delay(25);
    }

    //Only updating LCD when movement is there
    if (disPos != tempDisPos) {
      if (disPos == 0) {
        //Lazy fix
        lcd.clear();
        lcd.print("Hour Minutes");
        lcd.setCursor(0, 1);
        lcd.print("Seconds Mode");
      }
      else {
        lcd.clear();
        lcd.print(menu[disPos]);
        tempDisPos = disPos;
      }
      delay(50);
    }

    //Updating 8x8 when time changes
    DateTime now = rtc.now();
    int tempS = seconds;
    seconds = int(now.second());
    if (tempS != seconds)
      updateTime();

    if (checkButton()) {
      //Handling button press using the user position to pick a function to be ran
      switch (disPos) {
        case 0:
          delay(150);
          isFirstTime = true;
          displayMode = 0; break;
        case 1:
          delay(150);
          displayMode = 1; break;
        case 2:
          delay(150);
          displayMode = -1; break;
        case 3:
          delay(150);
          disMode = false; break;
        default:
          Serial.print("Error: ");
          Serial.println(disPos); break;
      }
    }
  }
}



//Settings Menu will show on LCD and be controlled by the Rot Enc
void displaySettings() {
  char *settings[] = {"Set Date", "Change Display Mode", "Exit Menu"};
  int settingLen = 2;                             //Prone to change with more features coming
  boolean settingsMode = true;
  int settingsPos = 0;                            //User position
  lcd.clear();
  lcd.print(settings[settingsPos]);               //Displaying user's postion in the menu
  delay(100);
  while (settingsMode) {
    dir = (int)(encoder->getDirection());       //updating direction to see if Rot Enc has been turned
    int tempSettingsPos = settingsPos;          //This is for making sure the user moved in the menu
    if (dir != 0) {                             //checking for movement
      if (dir < 0) {
        settingsPos += settingsPos > 0 ? dir : settingLen;  //making sure it doesn't go below 0 and wrap around
      } else {
        settingsPos += settingsPos < settingLen ? dir : -1 * settingLen;  //making it wrap around if it goes over the menu len
      }
      if (settingsPos > settingLen || settingsPos < 0) //fixing any crazy errors
        settingsPos = 0;
      delay(25);
    }

    //Only updating LCD when movement is there
    if (settingsPos != tempSettingsPos) {
      if (settingsPos == 1) {
        //another lazy fix
        lcd.clear();
        lcd.print("Change Display");
        lcd.setCursor(0, 1);
        lcd.print("Mode");
      }
      else {
        lcd.clear();
        lcd.print(settings[settingsPos]);
        tempSettingsPos = settingsPos;
      }
      delay(50);
    }

    //Updating 8x8 when time changes
    DateTime now = rtc.now();
    int tempS = seconds;
    seconds = int(now.second());
    if (tempS != seconds)
      updateTime();

    if (checkButton()) {
      //Handling button press using the user position to pick a function to be ran
      switch (settingsPos) {
        case 0:
          delay(150);
          setDate();
          settingsMode = false; break;
        case 1:
          delay(150);
          disSettings();
          settingsMode = false; break;
        case 2:
          delay(150);
          showDate();
          settingsMode = false; break;
        default:
          Serial.print("Error: ");
          Serial.println(settingsPos); break;
      }
    }
  }
}

//Simple function that checks for a button press and returns a bool
//has a bit of deboucing built in but may need more when implemented
boolean checkButton() {
  int switchState = digitalRead(SwitchPin);
  if (switchState == LOW) {
    delay(30);
    if (switchState == digitalRead(SwitchPin)) {
      return true;
    }
  }
  return false;
}

//Function to show hour on the 8x8 Display
void showHour() {
  int binToImgH[] = {0x00, 0x6, 0x60, 0x66};
  //The different states of the hour portion of the clock 00 01 10 11 in Hex (keep in mind this is for a column of a 8x8 diplsay
  //Formatted 0XX00XX0 on the 8x8
  float index = 0;
  for (int i = 0; i < 2; i++) //This for loop gets the lower half of a four bit number (Hour)
    index += ((hour >> i) & 1) * pow(2, i);
  for (int i = 7; i > 4; i--) //This for loop shows it on the right 8x8
    myDisplay.setColumn(0, i, binToImgH[index <= 3.0 ? (int)index : (int)index + 1]);

  index = 0;
  for (int i = 0; i < 2; i++)//This for loop gets the upper half of a four bit number (Hour) and shows it on the left side of the screen
    index += ((hour >> i + 2) & 1) * pow(2, i);
  for (int i = 7; i > 4; i-- )//This for loop shows it on the left 8x8
    myDisplay.setColumn(1, i, binToImgH[index <= 3.0 ? (int)index : (int)index + 1]);
}

//Function to show minutes on the 8x8 Display
void showMinute() {
  int binToImg[] = {0x00, 0x2, 0x18, 0x1A, 0x40, 0x42, 0x58, 0x5A};
  //Different states 000  001  010  011    100   101   110   111
  //Formatted 0X0XX0X0 on 8x8
  float index = 0;
  for (int i = 0; i < 3; i++) //This for loop gets the lower half of a six bit number (Minute)
    index += ((minute >> i) & 1) * pow(2, i);
  for (int i = 3; i > 1; i--) //This for loop shows the number on the right 8x8
    myDisplay.setColumn(0, i, binToImg[index <= 3.0 ? (int)index : (int)index + 1]);

  index = 0;

  for (int i = 0; i < 3; i++)//This for loop gets the upper half of a six bit number (Minute)
    index += ((minute >> i + 3) & 1) * pow(2, i);

  for (int i = 3; i > 1; i--)//This for loop shows the number on the left 8x8
    myDisplay.setColumn(1, i, binToImg[index <= 3.0 ? (int)index : (int)index + 1]);
}

//Function to show seconds on 8x8 Display
void showSecond() {
  int binToImg[] = {0x00, 0x2, 0x18, 0x1A, 0x40, 0x42, 0x58, 0x5A};
  char *testArr[] = {"000", "001", "010", "011", "100", "101", "110", "111"};
  //Different states 000  001  010  011    100   101   110   111
  //Formatted 0X0XX0X0 on 8x8
  float index = 0;
  for (int i = 0; i < 3; i++) //This for loop gets the lower half of a six bit number (Seconds)
      index += (seconds >> i & 1) * pow(2, i);
  //Displaying the seconds (Only gets one Col/Row depending on how you loop at it)
  myDisplay.setColumn(0, 0, binToImg[index <= 3.0 ? (int)index : (int)index + 1]);
 
  int tempIndex = index;
  float index2 = 0;
  for (int i = 0; i < 3; i++) //This for loop gets the upper half of the six bit number (Seconds)
    index2 += (seconds >> i + 3 & 1) * pow(2, i);
  Serial.print(testArr[(int)index2]);
  Serial.println(testArr[(int)index]);
  Serial.print((int)index);
  Serial.print(" ");
  Serial.println(index);
  //Displaying it
  myDisplay.setColumn(1, 0, binToImg[index2 <= 3.0 ? (int)index2 : (int)index2 + 1]);
}
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
void loop() {
  //Checking to see if the time changes to update seconds and other time
  DateTime now = rtc.now();
  int tempS = seconds;
  seconds = int(now.second());
  if (tempS != seconds)
    updateTime();

  //Checking for a button press to start menu with deboucing
  if (checkButton()) {
    delay(150);
    displaySettings();
  }
  else
    delay(50);
}

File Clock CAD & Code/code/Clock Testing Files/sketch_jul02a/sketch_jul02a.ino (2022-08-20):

#include <LiquidCrystal.h>

LiquidCrystal lcd(5, 6, 7, 12, 2, 4);

const char *daysOfTheWeek[] = {"N/A", "Sunday", "Monday", "Tuesday", "Wednesday", "Thursday", "Friday", "Saturday"};
const char *months[] = {"N/A", "Jan", "Feb", "Mar", "Apr", "May", "June", "July", "Aug",
                        "Sep", "Oct", "Nov", "Dec"};
int month = 1;
int day = 1;
int year = 2000;
int tempYear;


const char *dates[] = {"0", "1", "2", "3", "4", "5", "6", "7", "8", "9", "10", "11", "12", "13", "14", "15", "16", "17", "18", "19", "20", "21", "22", "23", "24", "25", "26", "27", "28", "29", "30", "31"};
char *date[] = {months[month], dates[day], daysOfTheWeek[day]};

int switchPin = 10;                        // button pin
int switchState = HIGH;                    // button value
volatile int counter = 0;
volatile int lastCounter = 0;
int CLK = 9;                              // Rotary encoder Pin A
int DT = 3;                              // Rotary encoder Pin B
int pinAstateCurrent = LOW;                // Current state of Pin A
int pinAStateLast = pinAstateCurrent;      // Last read value of Pin A


bool settingsMode = false;



void setup() {
  lcd.begin(16, 2);
  lcd.clear();


  // Setup Serial Monitor
  Serial.begin(9600);

  pinMode (switchPin, INPUT_PULLUP);       // Enable the switchPin as input with a PULLUP resistor
    
  pinMode (CLK, INPUT);                   // Set PinA as input
  pinMode (DT, INPUT);                   // Set PinB as input

  // Atach a CHANGE interrupt to PinB and exectute the update function when this change occurs.
  attachInterrupt(digitalPinToInterrupt(DT), updateRot, CHANGE);
  
}


void updateRot() {
  // ROTATION DIRECTION
  pinAstateCurrent = digitalRead(CLK);    // Read the current state of Pin A
  lastCounter = counter;
  // If there is a minimal movement of 1 step
  if ((pinAStateLast == LOW) && (pinAstateCurrent == HIGH)) {
    if (digitalRead(DT) == HIGH)        // If Pin B is HIGH
      counter++; //Right
    else 
      counter--; //Left
      }
  
  pinAStateLast = pinAstateCurrent;        // Store the latest read value in the currect state variable
  
}

int getWeekIndex(int m, int d, int y) {
  Serial.print("Dates given: ");
  Serial.print(m);
  Serial.print("-");
  Serial.print(d);
  Serial.print("-");
  Serial.println(y);  
    
  int monthKeys[] = {0, 1, 4, 4, 0, 2, 5, 0, 3, 6, 1, 4, 6};
  int index = String(y).substring(2).toInt();
  index = floor(index / 4);
  index += d;
  index += monthKeys[m];
  if ( m == 0 || ( m == 1 && y % 4 == 0 && (y % 100 != 0 || y % 400 == 0 && y % 100 == 0)))
    index--;
  int topTwo = floor(y / 100);
  while (topTwo < 20)
    topTwo += 4;
  if ((topTwo - 17) % 4 == 0)
    index += 4;
  else if ((topTwo - 18) % 4 == 0)
    index += 2;
  else if ((topTwo - 19) % 4 == 0)
    index += 0;
  else if ((topTwo - 20) % 4 == 0)
    index += 6;
  index += String(y).substring(2).toInt();
  index %= 7;

  return index;
}

void showDate(bool useTempYear) {
  lcd.clear();
  String topLine = String(date[0]) + " " + String(useTempYear ? tempYear : year) + " " + String(date[1]);
  String bottomLine = String(date[2]);
  for (int i = 0; i < 2; i++) {
    lcd.print(date[i]);
    lcd.print(" ");
  }
  lcd.print(useTempYear ? tempYear : year);
  lcd.print(" ");
  lcd.setCursor(0, 1);
  lcd.print(date[2]);
}



void configureTime() {
  Serial.print("TODO");
}


void formatDate(int m, int d, int y, bool updateYear) {
  date[0] = months[m];
  date[1] = dates[d];
  tempYear = y;
  year = updateYear ? y : year;
  int dayotw = getWeekIndex(m, d, y);
  date[2] = daysOfTheWeek[dayotw];
}

void formatDateM(int d, int y) {
  int dayotw = getWeekIndex(month, d, y);
  date[0] = char("<--");
  date[1] = dates[d];
  tempYear = y;
  date[2] = daysOfTheWeek[d];


}

void formateDateD(int m, int y) {
  int dayotw = getWeekIndex(m, day, y);
  date[0] = months[m];
  date[1] = char("<--");
  date[2] = daysOfTheWeek[dayotw];
  tempYear = year;
}

void formateDateY(int m, int d) {
  int dayotw = getWeekIndex(m, d, year);
  date[0] = months[m];
  date[1] = char("<--");
  date[1] = dates[d];
  date[2] = daysOfTheWeek[dayotw];
}

String getDirection(){
  if(counter != lastCounter)
    return counter > lastCounter ? "CW" : "CCW";
  return "No Turn";
}

void setDate() {
  lcd.clear();
  int setYear = year;
  int setMonth = month;
  int setDay = day;
  int mode = 0;
  Serial.println("Setting date");
  lastCounter = counter;

  while (true) {
    lcd.clear();
    int btnState = digitalRead(switchPin);
    showDate(false);
    if (lastCounter != counter) {
      String currentDir = getDirection();
      if (currentDir == "CCW")
        mode = mode > 0 ? mode-- : 3;
      else
        mode = mode < 3  ? mode++ : 0;
    }

    else if (btnState == LOW) {
      if (millis() - lastButtonPress > 50) {
        switch (mode) {
          case 0:
            Serial.println("Month Mode");
            while (true) {
              lcd.clear();
              handleRotary();
              if (lastCounter != counter) {
                currentDir = getDirection();
                if (currentDir == "CCW")
                  setMonth = setMonth > 1 ? setMonth-- : 13;
                else
                  setMonth = setMonth < 13  ? setMonth++ : 1;
              }

              else if (btnState == LOW) {
                if (millis() - lastButtonPress > 50) {
                  if (setMonth == 13) {
                    break;
                  }
                  else
                    month = setMonth;
                }
                lastButtonPress = millis();
              }
              if (setMonth == 13)
                formatDateM(setDay, setYear);
              else
                formatDate(setMonth, setDay, setYear, false);
              showDate(true);
            }
              
        }
      }
      lastButtonPress = millis();
    }


  }
}

void handleSettings() {
  char *settingsMenu[] = {"Set date", "Exit Menu"};
  lcd.clear();
  lcd.print(settingsMenu[0]);
  lastCounter = counter;
  int mode = 0;
  char prevState =  mode;
  while (settingsMode) {
    if (prevState != mode) {
      lcd.clear();
      lcd.print(settingsMenu[mode]);
    }
    int btnState = digitalRead(switchPin);
    if (lastCounter != counter) {
      String currentDir = getDirection();
      if (currentDir == "CCW")
        mode = mode > 0 ? mode-- : sizeof(settingsMenu) - 1;
      else
        mode = mode < sizeof(settingsMenu) - 1  ? mode++ : 0;
      delay(100);
    }


    else if (btnState == LOW) {
      if (millis() - lastButtonPress > 50) {
        switch (mode) {
          case 0: setDate();
          default: Serial.println("Nah");
        }
      }
      lastButtonPress = millis();
    }
    prevState = mode;
  }
}
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

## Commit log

2022-06-12 Uploaded Week1
    - Blinking LED code
    - Blinking LED Schema
    [Proto.kicad_sch]
2022-06-21 Week 2 work
    (I forgot to push this earlier oops)
    [Proto.kicad_sch]
2022-06-27 HMI Design added to KiCAD
    I need the Rotary Encoder for my schema
    [Proto.kicad_sch]
2022-07-02 Posted Week 4 and Possibly updated week3
    [Clock.csv, Clock.kicad_pcb, Clock.kicad_sch]
2022-07-07 Updated Schema & PCB
    PCB was completely redone with only two DRC warnings which pertain to the Power In but nothing big, Changed to smaller LCD (Thankfully more space)
    [Clock.csv, Clock.kicad_pcb, Clock.kicad_sch]
2022-07-07 Fixed major DRC issues
    Only DRC issues now are due to my logo :(
    [Clock.kicad_pcb]
2022-07-08 Fixed ALL DRC Warnings
    Mark the works of this Github Commit, this clock PCB will be amazing (Added proper logo to PCB and Schema)
    [Clock.kicad_pcb, Clock.kicad_sch]
2022-07-08 Added Fetus Arduino Code
    Baby Clock Code has been added
    [Clock.kicad_pcb, Clock.kicad_sch]
2022-07-08 Fixed Clock code and added copperto logo
    [Clock.csv, Clock.kicad_pcb]
2022-07-12 Week 6 Update* (Arduino Code)
    Added additional Display modes now including Decimal and Binary mode found at https://bryang229.github.io/8x8Demo/ :) now we have 3 different ways to read time !
    [Clock.kicad_pcb, Clock.kicad_sch]
2022-07-17 Added Rounded Tracing (Passing all DRC)
    It's so perty (pretty :))
    [Clock-B_Cu.gbr, Clock-B_Mask.gbr, Clock-B_Paste.gbr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]
2022-07-17 Rot Encoder Update
    [Clock.kicad_pcb, Clock.kicad_sch]
2022-07-19 Uploading some week 7 work
    DFM Passed with no show stoppers :). I will be pushing a week 7 folder soon with all the good stuff
    [Clock.kicad_pcb]
2022-07-20 Week 7 Update !
    It's great :smile:
    [Clock-B_Cu.gbr, Clock-B_Mask.gbr, Clock-B_Paste.gbr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]
2022-07-20 Pushed Arduino Code
    Added the code :)
2022-07-20 Fixed PCB & Gerber
    No more backsided SMT
    [Clock-B_Cu.gbr, Clock-B_Mask.gbr, Clock-B_Paste.gbr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]
2022-07-20 Fixed weeks
    Week 7 will now hold all future updates to the PCB ! (Including future weeks)
    [Clock-B_Cu.gbr, Clock-B_Mask.gbr, Clock-B_Paste.gbr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]
2022-07-20 Applied 12/12 rules
    Fix gerbers as well !
    [Clock-B_Cu.gbr, Clock-B_Mask.gbr, Clock-B_Paste.gbr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]
2022-07-21 Rounded Traces Gerber update
    [Clock-B_Cu.gbr, Clock-B_Mask.gbr, Clock-B_Paste.gbr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]
2022-07-21 Uploaded Student Designs :)
    [Clock-B_Cu.gbr, Clock-B_Mask.gbr, Clock-B_Paste.gbr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]
2022-07-21 Fixed week 7
    Accidentally worked in week 6 again but week 7 is the current folder again
    [Clock-B_Cu.gbr, Clock-B_Mask.gbr, Clock-B_Paste.gbr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]
2022-07-22 Late Student Design push
    [Clock-B_Cu.gbr, Clock-B_Mask.gbr, Clock-B_Paste.gbr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]
2022-07-22 Image update
    [Clock.kicad_pcb]
2022-07-22 Gave up on weeks
    [Clock-B_Cu.gbr, Clock-B_Mask.gbr, Clock-B_Paste.gbr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]
2022-07-22 Fixed DRC and ERC
    [Clock-B_Cu.gbr, Clock-B_Mask.gbr, Clock-B_Paste.gbr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]
2022-07-22 Fixed DRC and ERC issues
    Also added 12/12 rules
    [Clock-B_Cu.gbr, Clock-B_Mask.gbr, Clock-B_Paste.gbr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]
2022-07-22 Fixed some more issues
    [Clock-B_Cu.gbr, Clock-B_Mask.gbr, Clock-B_Paste.gbr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]
2022-07-22 Gerber gerber
    [Clock-B_Cu.gbr, Clock-B_Mask.gbr, Clock-B_Paste.gbr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]
2022-07-24 Fixed Binary conversion in code
    Float conversion to int causes an issue so you need to add one when the float > 3.0
    [ClockCodeVer1.ino]
2022-07-24 Fixed small syntax issue
    [ClockCodeVer1.ino]
